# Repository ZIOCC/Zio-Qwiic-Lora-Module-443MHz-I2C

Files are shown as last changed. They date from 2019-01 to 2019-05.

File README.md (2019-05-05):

# Zio-Qwiic-Lora-Module-443MHz-I2C

The gateway firmware referred [Sparkfun's QwiicRF](https://github.com/sparkfunx/Qwiic_RF)

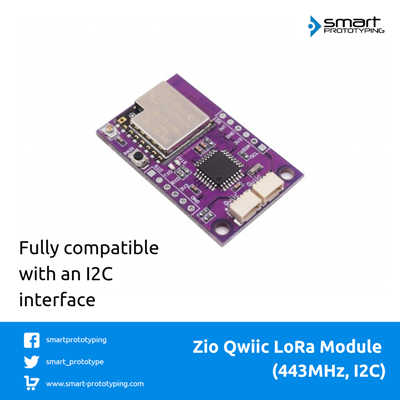
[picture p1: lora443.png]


> This product can be available for purchase [here](https://www.smart-prototyping.com/Zio-Qwiic-Lora-module-443MHz-I2C).

##### Description

This is a [Qwiic](https://www.smart-prototyping.com/Qwiic.html) version LoRa module, no soldering and jumper wire connections, just [Qwiic cable](https://www.smart-prototyping.com/zio-cables) plugin, and have fun! 

LoRa module is powerful, it can send and receive data packets at up to 10KM distance, and consumes very low power (10mA for receiver, 120mA for transmitter).

LoRa itself is a SPI device, in order to turn it into a I2C device, we added an MCU as the gateway to do the dirty work for you, you just need to use the module’s I2C interface to communicate with the others. It is just that easy.

> Note: This LoRa module is based on the LoRa-01 module, the frequency range is 420 - 450 MHz, check [here](https://www.thethingsnetwork.org/docs/lorawan/frequencies-by-country.html) to see if this can be used in your country.

##### Specification

* Voltage: 3.3V
* Interface: I2C
* I2C Address: 0x35, 0x36 (Default: 0x35)
* Distance: Up to 10KM
* Gateway MCU: ATMEGA328P
* Dimension: 26.0 x 41.6 mm
* Weight: 5.3g

##### Links

* [PCB Source file](https://github.com/ZIOCC/Zio-Qwiic-Lora-Module-443MHz-I2C/tree/master/EAGLE)
* [PCB schematic](https://github.com/ZIOCC/Zio-Qwiic-Lora-Module-443MHz-I2C/blob/master/zio%20qwiic%20lora%20module%20433%20schematic.pdf)
* [Demo code](https://github.com/sparkfun/SparkFun_QwiicRF_Library/)
* [Gateway firmware](https://github.com/ZIOCC/Zio-Qwiic-Lora-Module-443MHz-I2C/tree/master/Gateway_Firmware/Qwiic_RF_I2C_Pairing)

> ###### About Zio
> Zio is a new line of open sourced, compact, and grid layout boards, fully integrated for Arduino and Qwiic ecosystem. Designed ideally for wearables, robotics, small-space limitations or other on the go projects. Check out other awesome Zio products [here](https://www.smart-prototyping.com/Zio).

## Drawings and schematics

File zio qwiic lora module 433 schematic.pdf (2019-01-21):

# GND¹⁰⁰nF ±10% ⁵⁰V

# ATMEGA328P ¹⁰K ±1%

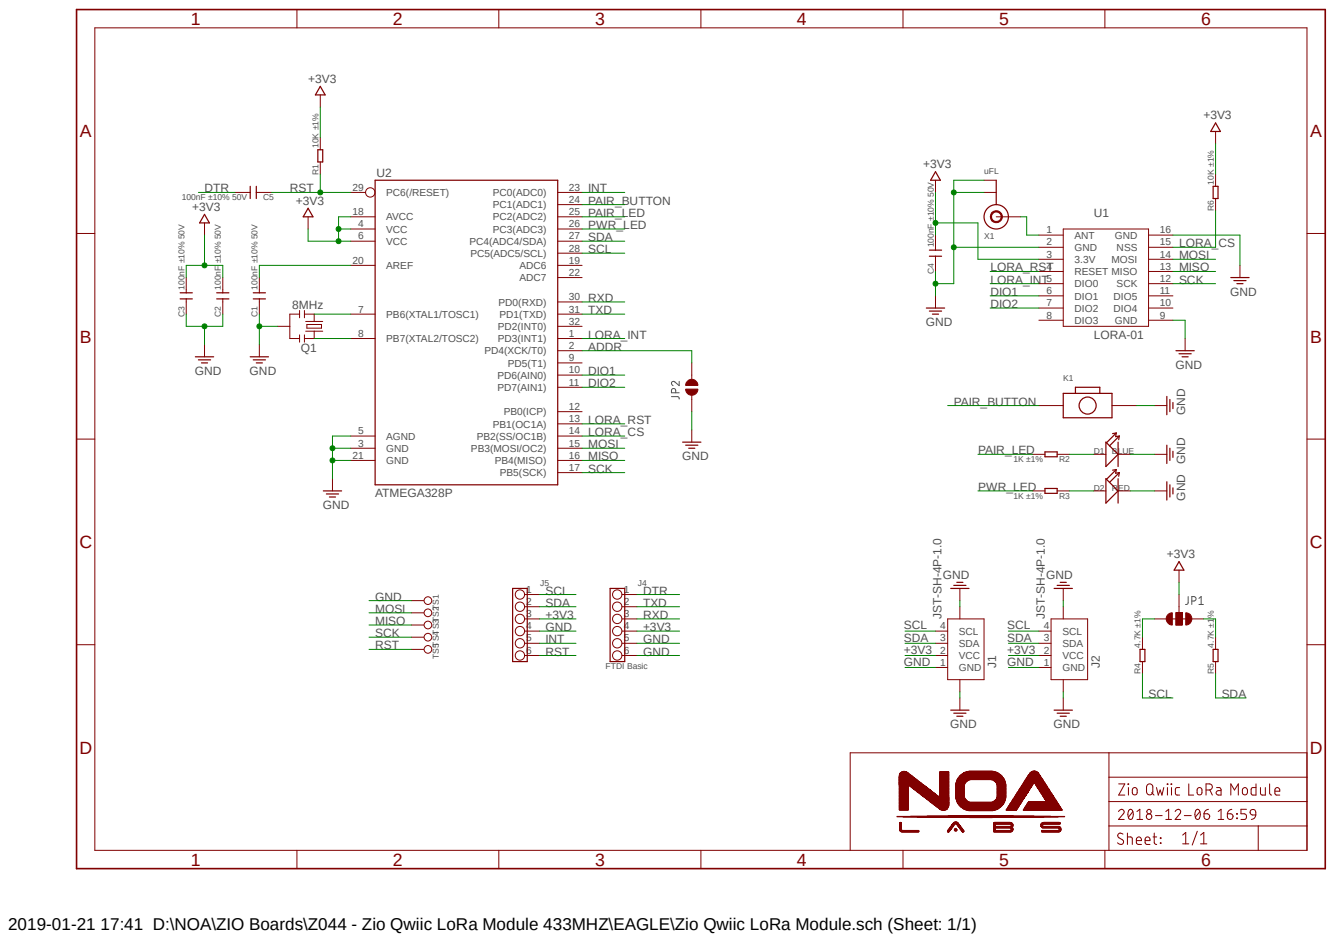
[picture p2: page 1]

2019-01-21 17:41 D:\NOA\ZIO Boards\Z044 - Zio Qwiic LoRa Module 433MHZ\EAGLE\Zio Qwiic LoRa Module.sch (Sheet: 1/1)

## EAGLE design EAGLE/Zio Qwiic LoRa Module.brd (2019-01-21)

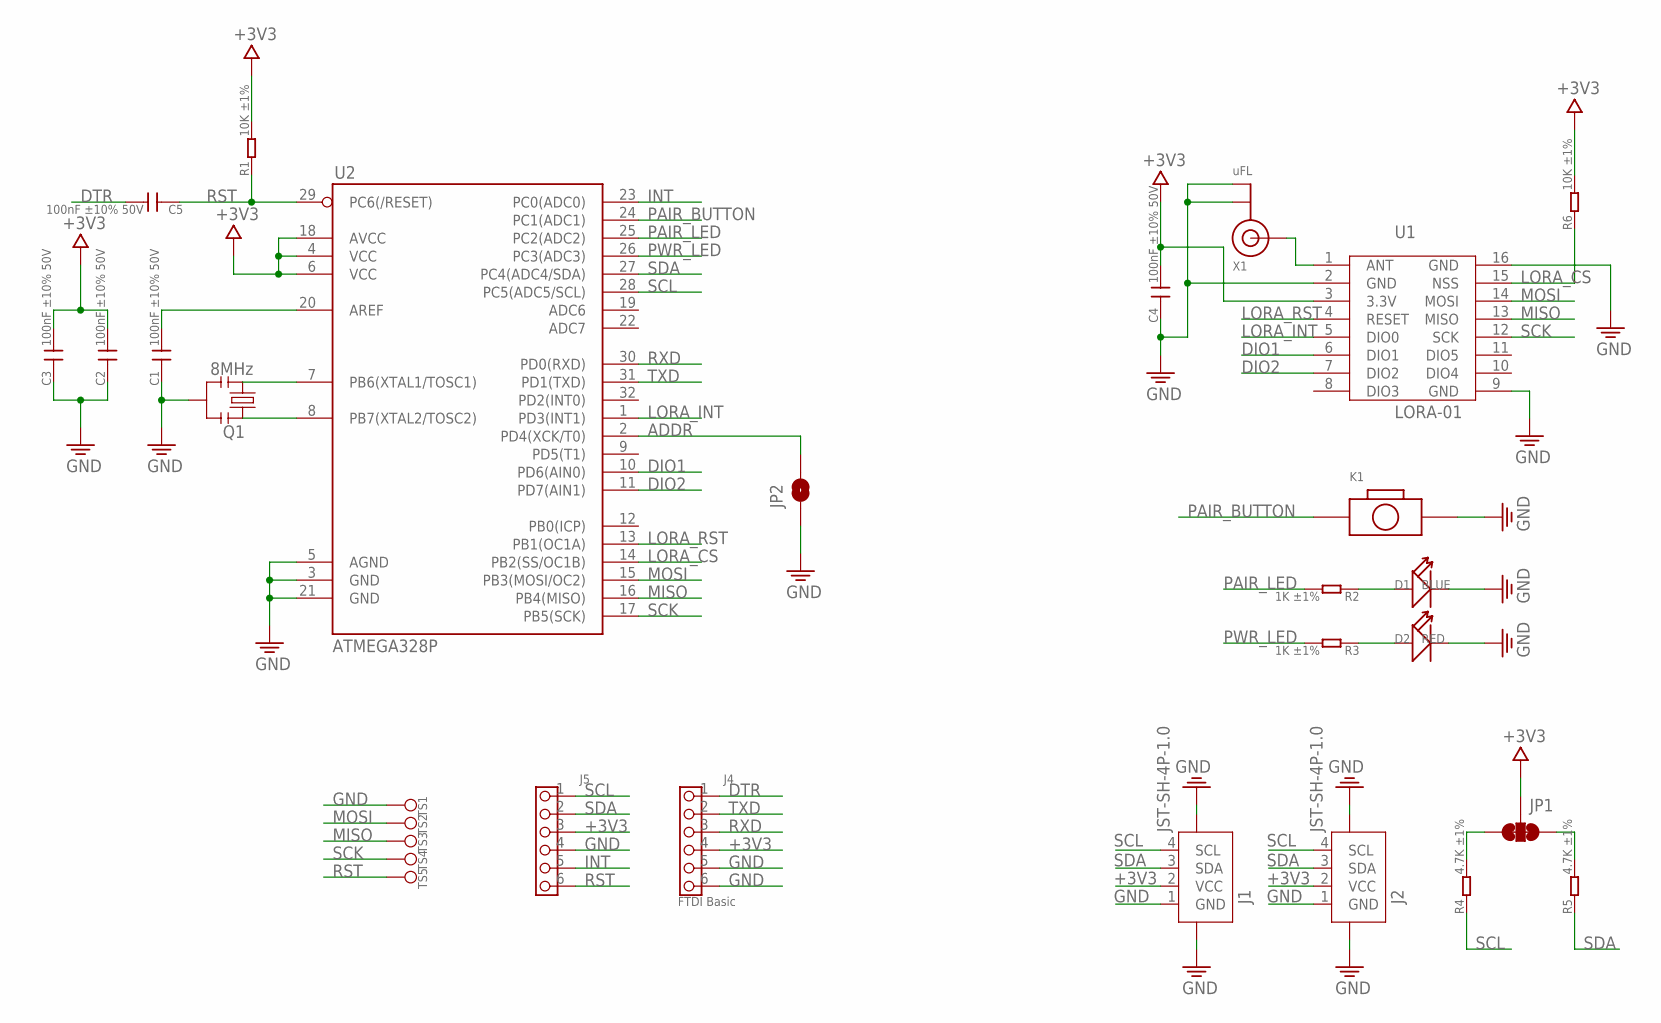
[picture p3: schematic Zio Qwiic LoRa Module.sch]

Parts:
C1, C2, C3, C4, C5: 100nF ±10% 50V; C0603
D1: BLUE; LED-0603
D2: RED; LED-0603
J1, J2: JST-SH-4P-1.0; JST-SH-4P
J4: FTDI Basic; 6P-2.54-60/35MIL
J5: HEADER-6P-60/35MIL; 6P-2.54-60/35MIL
JP1: SMT-JUMPER_3_2-NC_TRACE
JP2: JUMPER-SMT_2_NC_PASTE_NOCREM; SMT-JUMPER_2_NC_PASTE_SILK_NOCREM
K1: BOTTON-2PSKRKAEE020; SKRKAEE020
Q1: 8MHz; RESONATOR-SMD
R1, R6: 10K ±1%; R0603
R2, R3: 1K ±1%; R0603
R4, R5: 4.7K ±1%; R0603
TS1, TS2, TS3, TS4, TS5: TEST_POINT35MIL; 1P-35MIL
U1: LORA-01
U2: ATMEGA328P; TQFP32-08
X1: uFL; U.FL

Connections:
+3V3: C2.2, C3.2, C4.2, J1.2 (VCC), J2.2 (VCC), J4.4, J5.3, JP1.2, R1.2, R6.2, U1.3 (3.3V), U2.4 (VCC), U2.6 (VCC), U2.18 (AVCC)
ADDR: JP2.2, U2.2 (PD4(XCK/T0))
DIO1: U1.6 (DIO1), U2.10 (PD6(AIN0))
DIO2: U1.7 (DIO2), U2.11 (PD7(AIN1))
DTR: C5.2, J4.1
GND: C1.1, C2.1, C3.1, C4.1, D1.-, D2.-, J1.1 (GND), J1.NC1 (5), J1.NC2 (6), J2.1 (GND), J2.NC1 (5), J2.NC2 (6), J4.5, J4.6, J5.4, JP2.1, K1.2, Q1.2, TS1.P$1, U1.2 (GND), U1.9 (GND), U1.16 (GND), U2.3 (GND), U2.5 (AGND), U2.21 (GND), X1.1 (GND), X1.2 (GND)
INT: J5.5, U2.23 (PC0(ADC0))
LORA_CS: R6.1, U1.15 (NSS), U2.14 (PB2(SS/OC1B))
LORA_INT: U1.5 (DIO0), U2.1 (PD3(INT1))
LORA_RST: U1.4 (RESET), U2.13 (PB1(OC1A))
MISO: TS3.P$1, U1.13 (MISO), U2.16 (PB4(MISO))
MOSI: TS2.P$1, U1.14 (MOSI), U2.15 (PB3(MOSI/OC2))
unnamed: D1.+, R2.1
unnamed: D2.+, R3.1
unnamed: Q1.3, U2.7 (PB6(XTAL1/TOSC1))
unnamed: Q1.1, U2.8 (PB7(XTAL2/TOSC2))
unnamed: C1.2, U2.20 (AREF)
unnamed: U1.1 (ANT), X1.3 (SIGNAL)
unnamed: JP1.3, R4.2
unnamed: JP1.1, R5.2
PAIR_BUTTON: K1.1, U2.24 (PC1(ADC1))
PAIR_LED: R2.2, U2.25 (PC2(ADC2))
PWR_LED: R3.2, U2.26 (PC3(ADC3))
RST: C5.1, J5.6, R1.1, TS5.P$1, U2.29 (PC6(/RESET))
RXD: J4.3, U2.30 (PD0(RXD))
SCK: TS4.P$1, U1.12 (SCK), U2.17 (PB5(SCK))
SCL: J1.4 (SCL), J2.4 (SCL), J5.1, R4.1, U2.28 (PC5(ADC5/SCL))
SDA: J1.3 (SDA), J2.3 (SDA), J5.2, R5.1, U2.27 (PC4(ADC4/SDA))
TXD: J4.2, U2.31 (PD1(TXD))

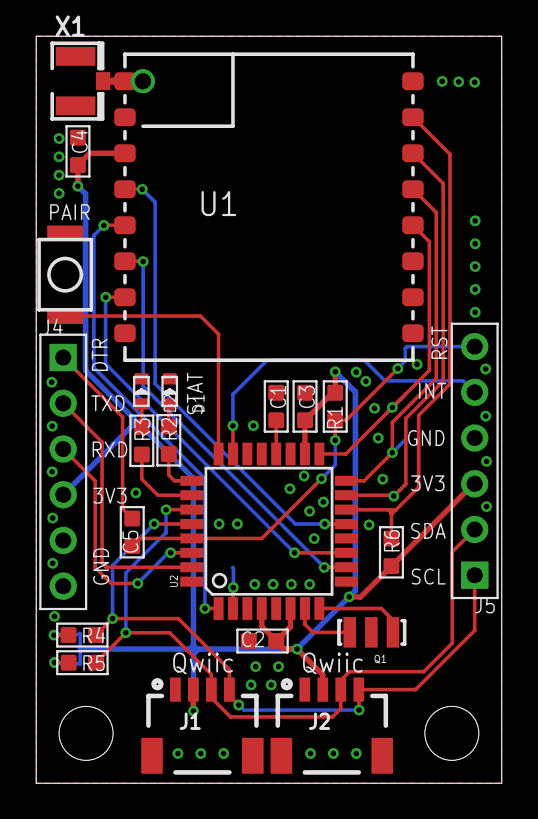
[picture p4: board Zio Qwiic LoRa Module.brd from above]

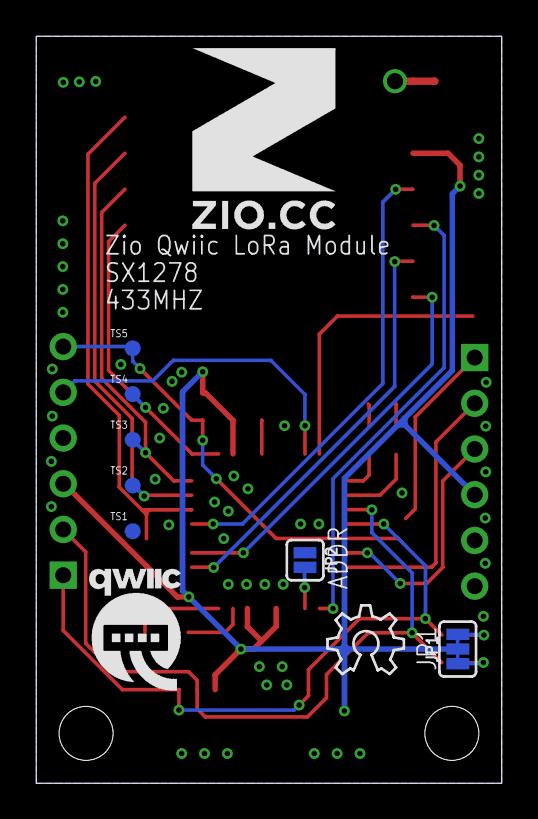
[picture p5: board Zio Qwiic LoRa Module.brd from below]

Board: 2 copper layers, 25.9 x 41.5 mm, 32 parts (10 on the bottom side), 29 nets.

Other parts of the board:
U$10: 10MM
U$11: QWIIC-LOGO-MEDIUM
U$12: OSHW_6X150_NOTEXT

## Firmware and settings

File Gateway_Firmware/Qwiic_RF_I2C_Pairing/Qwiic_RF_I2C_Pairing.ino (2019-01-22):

#include <Wire.h> //Need this for I2C
#include <EEPROM.h> //Need this for EEPROM Read/Write
#include <SPI.h> //Need this to talk to the radio
#include <LoRa.h> //https://github.com/sandeepmistry/arduino-LoRa

//Location in EEPROM where various settings will be stored
#define LOCATION_I2C_ADDR 0x01
#define LOCATION_RADIO_ADDR 0x02
#define LOCATION_SYNC_WORD 0x03
#define LOCATION_SPREAD_FACTOR 0x04
#define LOCATION_MESSAGE_TIMEOUT 0x05
#define LOCATION_TX_POWER 0x06
#define LOCATION_PAIRED_ADDRESS 0x07

//There is an ADR jumpber on this board. When closed, forces I2C address to default.
#define I2C_ADDRESS_DEFAULT 0x35
#define I2C_ADDRESS_JUMPER_CLOSED 0x36

//These are the commands we understand and may respond to
#define COMMAND_GET_STATUS 0x01
#define COMMAND_SEND 0x02
#define COMMAND_SEND_RELIABLE 0x03
#define COMMAND_SET_RELIABLE_TIMEOUT 0x04
#define COMMAND_GET_PAYLOAD 0x05
#define COMMAND_SET_SPREAD_FACTOR 0x06
#define COMMAND_SET_SYNC_WORD 0x07
#define COMMAND_GET_SYNC_WORD 0x11
#define COMMAND_SET_RF_ADDRESS 0x08
#define COMMAND_GET_RF_ADDRESS 0x09
#define COMMAND_GET_PACKET_RSSI 0x0A
#define COMMAND_GET_PAYLOAD_SIZE 0x0B
#define COMMAND_GET_PACKET_SENDER 0x0C
#define COMMAND_GET_PACKET_RECIPIENT 0x0D
#define COMMAND_GET_PACKET_SNR 0x0E
#define COMMAND_GET_PACKET_ID 0x0F
#define COMMAND_SET_TX_POWER 0x10
#define COMMAND_SET_I2C_ADDRESS 0x20
#define COMMAND_SET_PAIRED_ADDRESS 0x12
#define COMMAND_GET_PAIRED_ADDRESS 0x13
#define COMMAND_GET_SKU 0x15
#define COMMAND_SEND_PAIRED 0x20
#define COMMAND_SEND_RELIABLE_PAIRED 0x30

//These will help us keep track of how to respond to requests
#define RESPONSE_TYPE_STATUS 0x00
#define RESPONSE_TYPE_PAYLOAD 0x01
#define RESPONSE_TYPE_RF_ADDRESS 0x02
#define RESPONSE_TYPE_PACKET_RSSI 0x03
#define RESPONSE_TYPE_PACKET_SIZE 0x04
#define RESPONSE_TYPE_PACKET_SENDER 0x05
#define RESPONSE_TYPE_PACKET_RECIPIENT 0x06
#define RESPONSE_TYPE_PACKET_SNR 0x07
#define RESPONSE_TYPE_PACKET_ID 0x08
#define RESPONSE_TYPE_SYNC_WORD 0x09
#define RESPONSE_TYPE_PAIRED_ADDRESS 0x10
#define RESPONSE_TYPE_SKU 0x11

//A Few Pin Definitions
#define ADR_JUMPER 4
#define PAIR_BTN A1
#define PAIR_LED A2
#define PWR_LED A3

//Firmware version. This is sent when requested. Helpful for tech support.
const byte firmwareVersionMajor = 0;
const byte firmwareVersionMinor = 5;
char SKU[] = "14788";

//RFM95 pins
const int csPin = 10;          // LoRa radio chip select
const int resetPin = 9;       // LoRa radio reset
const int irqPin = 3;         // change for your board; must be a hardware interrupt pin

//*** These get twiddled during interrupts so they're type volatile ***

//System status variable
//Bit 0 - Ready To Send
//Bit 1 - Packet Available
//Bit 2 - Waiting on Reliable Send
//Bit 3 - Reliable Send Timeout
volatile byte systemStatus = 0b00000000;
//This global is used to keep track of the I2C Address (Software Switchable)
volatile byte settingI2CAddress = I2C_ADDRESS_DEFAULT;
//These globals are used for the "Reliable Send" routine
volatile unsigned long reliableSendTime = 0x00;
volatile unsigned long reliableResend = 0x00;
volatile byte reliableSendChk = 0x00;

//*** ***

//These are the radio parameters that are used to
//Initialize the RFM95. We assign them default
//values so we can load EEPROM on first boot.
byte settingRFAddress = 0xBB;
byte settingSyncWord = 0x34;
byte settingSpreadFactor = 0x07;
byte settingMessageTimeout = 0x0A;
byte settingTXPower = 0x11;
byte settingPairedAddress = 0xBB;
byte msgCount = 0x00;

//This is a type for storing radio packets
typedef struct {
  byte id;
  byte sender;
  byte recipient;
  byte snr;
  byte rssi;
  byte reliable;
  byte payloadLength;
  String payload;
} packet;

//Let's initialize a few instances of our new type
packet lastReceived = {0, 0, 0, 0, 0, 0, 0, ""};
packet lastSent = {0, 0, 0, 0, 0, 0, 0, ""};
packet outbox = {0, 0, 0, 0, 0, 0, 0, ""};

//Counter for the Pairing Button Hold-down
uint16_t pair_hold = 0;

//This will help us keep track of how to respond to requests
byte responseType = RESPONSE_TYPE_STATUS;

//This flag will tell the main loop when an outgoing packet is waiting for the radio
boolean outbox_waiting = 0;

//This flag will tell the main loop to mark the beginning of a reliable send cycle
boolean mark_time_reliable = 0;

void setup()
{
    
  //Set pin modes
  pinMode(PAIR_BTN, INPUT_PULLUP);
  pinMode(ADR_JUMPER, INPUT_PULLUP);
  pinMode(PAIR_LED, OUTPUT);
  pinMode(PWR_LED, OUTPUT);

  readSystemSettings(); //Load all system settings from EEPROM

  // override the default CS, reset, and IRQ pins (optional)
  LoRa.setPins(csPin, resetPin, irqPin);// set CS, reset, IRQ pin

  if (!LoRa.begin(433E6)) { //Initialize ratio at 433 MHz
    while (true) {
      //If failed, blink power LED
      digitalWrite(PWR_LED, 1);
      delay(500);
      digitalWrite(PWR_LED, 0);
      delay(500);
    };
  } else {
    //If successful, light power LED
    digitalWrite(PWR_LED, 1);
  }

  //Set our radio parameters from the stored values
  LoRa.setSyncWord(settingSyncWord);
  LoRa.setSpreadingFactor(settingSpreadFactor);
  LoRa.setTxPower(settingTXPower);

  LoRa.enableCrc();

  //Begin listening on I2C only after we've setup all our config and opened any files
  startI2C(); //Determine the I2C address we should be using and begin listening on I2C bus
  systemStatus |= 1 << 0; //Set "Ready" Status Flag
}

void loop()
{

  //If we just started a reliable send cycle, we need to mark the start time.
  //We do it here instead of immediately after getting the command so that we aren't
  //loading an unsigned long during an ISR
  if (mark_time_reliable) {
    systemStatus |= 1 << 2; //Set "Waiting on Reliable Send" Status Flag
    reliableSendTime = reliableResend = millis();
    mark_time_reliable = 0;
  }

  //If there is a "Waiting on Reliable Send" flag and the ack timer has expired,
  //remove the flag and set the "Reliable Send Timeout" flag instead.
  if ( ( (systemStatus >> 2) & 1 ) && ( millis() > ( reliableSendTime + ( settingMessageTimeout * 1000 ) ) ) ) {
    systemStatus &= ~(1 << 2); //Clear "Waiting on Reliable Send" Status Flag
    systemStatus |= 1 << 0; //Set "Ready" Status Flag
    systemStatus |= 1 << 3; //Set "Reliable Send Timeout" Status Flag
    reliableSendChk = 0x00; //Reset Checksum accumulator
    reliableSendTime = 0x00; //Reset reliableSendTime timestamp
    reliableResend = 0x00; //Reset reliableResend timestamp
    //If there is a "Waiting on Reliable Send" flag and the ack timer has NOT expired,
    //check the reliable send interval counter and possibly try resending.
  } else if ( ( (systemStatus >> 2) & 1 ) && ( millis() < ( reliableSendTime + ( settingMessageTimeout * 1000 ) ) ) ) {
    if ( millis() > reliableResend + 1000 ) { //Retry once per second
      sendMessage(lastSent.recipient, 0, lastSent.payload);
      reliableResend = millis();
    }
  }

  //If the pairing button is being held
  if ( digitalRead(PAIR_BTN) == 0 ) {
    pair_hold++;
    if (pair_hold > 5000) {
      pair_hold = 0;
      pairingSequence();
    }
  } else {
    pair_hold = 0;
  }

  if (outbox_waiting) {
    sendMessage(outbox.recipient, outbox.reliable, outbox.payload);
    outbox_waiting = 0;
    systemStatus |= 1 << 0; //Set "Ready" Status Flag
  }

  onReceive(LoRa.parsePacket());
}

//Send a message via the radio
void sendMessage(byte destination, byte reliable, String outgoing)
{
  digitalWrite(PAIR_LED, 1);
  LoRa.beginPacket();                   // start packet
  LoRa.write(destination);              // add destination address
  LoRa.write(settingRFAddress);         // add sender address
  LoRa.write(msgCount);                 // add message ID
  LoRa.write(reliable);                 // add reliable send tag
  LoRa.write(outgoing.length());        // add payload length
  LoRa.print(outgoing);                 // add payload
  LoRa.endPacket();                     // finish packet and send it

  lastSent.id = msgCount;
  lastSent.sender = settingRFAddress;
  lastSent.recipient = destination;
  lastSent.payloadLength = outgoing.length();
  lastSent.payload = outgoing;
  lastSent.reliable = reliable;

  msgCount++;                           // increment message ID
  digitalWrite(PAIR_LED, 0);
}

//Check for a new radio packet, parse it, store it
void onReceive(int packetSize) {
  if (packetSize == 0) return;          // if there's no packet, return

  digitalWrite(PAIR_LED, 1);
  // read packet header bytes:
  int recipient = LoRa.read();          // recipient address
  byte sender = LoRa.read();            // sender address
  byte incomingMsgId = LoRa.read();     // incoming msg ID
  byte reliable = LoRa.read();          // reliable send tag
  byte incomingLength = LoRa.read();    // incoming msg length

  String incoming = "";

  while (LoRa.available()) {
    incoming += (char)LoRa.read();
  }

  digitalWrite(PAIR_LED, 0);

  if (incomingLength != incoming.length()) {   // check length for error
    return; //Get outta here
  }

  //If the packet isn't addressed to this device or the broadcast channel,
  if (recipient != settingRFAddress && recipient != 0xFF) {
    return; //Get outta here
  }

  //If the message is for this device, or broadcast, store it appropriately:
  lastReceived.id = incomingMsgId;
  lastReceived.sender = sender;
  lastReceived.recipient = recipient;
  lastReceived.snr = LoRa.packetSnr();
  lastReceived.rssi = LoRa.packetRssi();
  lastReceived.payloadLength = incomingLength;
  lastReceived.payload = incoming;
  lastReceived.reliable = reliable;

  //If we're waiting on a Reliable Send ack, check to see if this is it.
  //A Reliable Send Ack payload has two bytes:
  //Byte 1: SNR of Reliable Packet
  //Byte 2: RSSI of Reliable Packet
  if ( (systemStatus >> 2) & 1 ) {

    //If the fourth byte of the header is equal to the sum of
    //the last sent message, we have Reliable Ack.
    if ( reliable == reliableSendChk ) {

      reliableSendChk = 0x00; //Reset Checksum accumulator
      reliableSendTime = 0x00; //Reset reliableSendTime timestamp
      reliableResend = 0x00; //Reset reliableResend timestamp
      systemStatus &= ~(1 << 2); //Clear "Waiting on Reliable Send" Status Flag
      systemStatus |= 1 << 0; //Set "Ready" Status Flag
      systemStatus &= ~(1 << 3); //Clear "Reliable Send Timeout" Status Flag

      //Grab these tidbits in case anyone wants them
      lastSent.snr = incoming.charAt(0);
      lastSent.rssi = incoming.charAt(1);

    }
  }

  //If this was a Reliable type message, calculate checksum and reply
  if ( reliable == 1 ) {

    String response = "";
    byte reliableAckChk = 0;
    //Calculate simple checksum of payload, reliableSendChk is type byte
    //so for sake of cycles, we will let it roll instead of explicitly
    //calculating (sum payload % 256)
    for ( int symbol = 0; symbol < incomingLength; symbol++ ) {
      reliableAckChk += incoming.charAt(symbol);
    }
    //Because we use values 0 and 1 for signalling, we ensure that the
    //checksum can never be < 1
    if ( reliableAckChk < 254 ) {
      reliableAckChk += 2;
    }
    response = lastReceived.snr;
    response += lastReceived.rssi;
    //Return to Sender
    sendMessage(sender, reliableAckChk, response);

  }

  //Set the "New Payload" Status Flag
  systemStatus |= 1 << 1;
}

//Read an I2C Request from the master
void receiveEvent(int numberOfBytesReceived)
{
  //Record bytes to local array
  byte incoming = Wire.read();

  //Set new I2C address
  if (incoming == COMMAND_SET_I2C_ADDRESS)
  {
    if (Wire.available())
    {
      settingI2CAddress = Wire.read();

      //Error check
      if (settingI2CAddress < 0x08 || settingI2CAddress > 0x77)
        return; //Command failed. This address is out of bounds.

      EEPROM.write(LOCATION_I2C_ADDR, settingI2CAddress);

      //Our I2C address may have changed because of user's command
      startI2C(); //Determine the I2C address we should be using and begin listening on I2C bus
    }
  }
  //Return the current system status
  else if (incoming == COMMAND_GET_STATUS)
  {
    responseType = RESPONSE_TYPE_STATUS;
  }
  //Send a payload via the radio
  else if (incoming == COMMAND_SEND)
  {

    if (Wire.available() > 1) {

      byte recipient = Wire.read();

      String payload = "";

      while (Wire.available()) {
        payload += (char)Wire.read();
      }

      queueMessage(recipient, 0, payload);

    }

  }
  //Send a payload via the radio to the last
  //paired address
  else if (incoming == COMMAND_SEND_PAIRED)
  {

    if (Wire.available() > 1) {

      String payload = "";

      while (Wire.available()) {
        payload += (char)Wire.read();
      }

      queueMessage(settingPairedAddress, 0, payload);

    }

  }  
  //Send a payload via the radio and request ack
  else if (incoming == COMMAND_SEND_RELIABLE)
  {

    if (Wire.available() > 1) {

      byte recipient = Wire.read();

      String payload = "";

      while (Wire.available()) {
        payload += (char)Wire.read();
      }

      queueMessage(recipient, 1, payload);

      //Reset checksum accumulator
      reliableSendChk = 0;

      //Calculate simple checksum of payload, reliableSendChk is type byte
      //so for sake of cycles, we will let it roll instead of explicitly
      //calculating (sum payload % 256)
      for ( int symbol = 0; symbol < payload.length(); symbol++ ) {
        reliableSendChk += payload.charAt(symbol);
      }

      //Because we use values 0 and 1 for signalling, we ensure that the
      //checksum can never be < 1
      if ( reliableSendChk < 254 ) {
        reliableSendChk += 2;
      }

      mark_time_reliable = 1;

    }

  }
  //Send a payload via the radio to the last paired
  //address and request ack
  else if (incoming == COMMAND_SEND_RELIABLE_PAIRED)
  {

    if (Wire.available() > 1) {

      String payload = "";

      while (Wire.available()) {
        payload += (char)Wire.read();
      }

      queueMessage(settingPairedAddress, 1, payload);

      //Reset checksum accumulator
      reliableSendChk = 0;

      //Calculate simple checksum of payload, reliableSendChk is type byte
      //so for sake of cycles, we will let it roll instead of explicitly
      //calculating (sum payload % 256)
      for ( int symbol = 0; symbol < payload.length(); symbol++ ) {
        reliableSendChk += payload.charAt(symbol);
      }

      //Because we use values 0 and 1 for signalling, we ensure that the
      //checksum can never be < 1
      if ( reliableSendChk < 254 ) {
        reliableSendChk += 2;
      }

      mark_time_reliable = 1;

    }

  }  
  //Set the time in seconds to wait for reliable ack before failing
  else if (incoming == COMMAND_SET_RELIABLE_TIMEOUT)
  {

    if (Wire.available()) {
      settingMessageTimeout = Wire.read();
      EEPROM.write(LOCATION_MESSAGE_TIMEOUT, settingMessageTimeout);
    }

  }
  //Store the address of a paired radio
  else if (incoming == COMMAND_SET_PAIRED_ADDRESS)
  {

    if (Wire.available()) {
      settingPairedAddress = Wire.read();
      EEPROM.write(LOCATION_PAIRED_ADDRESS, settingPairedAddress);
    }

  }
  //Return the address of a paired radio
  else if (incoming == COMMAND_GET_PAIRED_ADDRESS)
  {

    responseType = RESPONSE_TYPE_PAIRED_ADDRESS;

  }  
  //Return the payload of the last received packet
  else if (incoming == COMMAND_GET_PAYLOAD)
  {

    responseType = RESPONSE_TYPE_PAYLOAD;

  }
  //Set the spread factor of the radio
  else if (incoming == COMMAND_SET_SPREAD_FACTOR)
  {

    if (Wire.available()) {
      byte newSpreadFactor = Wire.read();

      if (newSpreadFactor > 12 || newSpreadFactor < 6) {
        return;
      }

      settingSpreadFactor = newSpreadFactor;
      EEPROM.write(LOCATION_SPREAD_FACTOR, settingSpreadFactor);
      LoRa.setSpreadingFactor(settingSpreadFactor);
    }

  }
  //Set the Sync Word of the radio
  else if (incoming == COMMAND_SET_SYNC_WORD)
  {
    if (Wire.available()) {
      settingSyncWord = Wire.read();
      EEPROM.write(LOCATION_SYNC_WORD, settingSyncWord);
      LoRa.setSyncWord(settingSyncWord);
    }

  }
  //Set the Address of the radio
  else if (incoming == COMMAND_SET_RF_ADDRESS)
  {

    if (Wire.available()) {
      byte newRFAddress = Wire.read();

      if (newRFAddress < 0xFF) { //0xFF is Broadcast Channel
        settingRFAddress = newRFAddress;
        EEPROM.write(LOCATION_RADIO_ADDR, settingRFAddress);
      }
    }

  }
  //Return the Address of the radio
  else if (incoming == COMMAND_GET_RF_ADDRESS)
  {

    responseType = RESPONSE_TYPE_RF_ADDRESS;
    return;

  }
  //Return the RSSI of the last received packet
  else if (incoming == COMMAND_GET_PACKET_RSSI)
  {

    responseType = RESPONSE_TYPE_PACKET_RSSI;
    return;

  }
  //Return the size of the payload of the last received packet
  else if (incoming == COMMAND_GET_PAYLOAD_SIZE)
  {

    responseType = RESPONSE_TYPE_PACKET_SIZE;
    return;

  }
  //Return the origin address of the last received packet
  else if (incoming == COMMAND_GET_PACKET_SENDER)
  {

    responseType = RESPONSE_TYPE_PACKET_SENDER;
    return;

  }
  //Return the destination address of the last received packet
  else if (incoming == COMMAND_GET_PACKET_RECIPIENT)
  {

    responseType = RESPONSE_TYPE_PACKET_RECIPIENT;
    return;

  }
    else if (incoming == COMMAND_GET_SYNC_WORD)
  {

    responseType = RESPONSE_TYPE_SYNC_WORD;
    return;

  }
  //Return the SNR (Signal-to-Noise Ratio) of the last received packet
  else if (incoming == COMMAND_GET_PACKET_SNR)
  {

    responseType = RESPONSE_TYPE_PACKET_SNR;
    return;

  }
  //Return the sequential ID of the last received packet
  else if (incoming == COMMAND_GET_PACKET_ID)
  {

    responseType = RESPONSE_TYPE_PACKET_ID;
    return;

  }
  //Return the SKU of this product. Used to identify
  //other radios on the bus during pairing operations.
  else if (incoming == COMMAND_GET_SKU)
  {

    responseType = RESPONSE_TYPE_SKU;
    return;

  }
  //Adjust the radio transmit amplifier
  else if (incoming == COMMAND_SET_TX_POWER)
  {

    byte txPower = Wire.read();
    if (txPower > 17) {
      txPower = 17;
    }
    settingTXPower = txPower;
    EEPROM.write(LOCATION_TX_POWER, settingTXPower);
    LoRa.setTxPower(txPower);

  }
}

//Respond to I2C master's request for bytes
void requestEvent()
{
  //Return system status byte
  if (responseType == RESPONSE_TYPE_STATUS)
  {
    Wire.write(systemStatus);
  }
  //Return payload of last received packet
  else if (responseType == RESPONSE_TYPE_PAYLOAD)
  {

    for (byte len = 0; len < lastReceived.payloadLength; len++) {
      Wire.write(lastReceived.payload.charAt(len));
    }

    responseType = RESPONSE_TYPE_STATUS;
    systemStatus &= ~(1 << 1); //Clear "New Payload" Status Flag
  }
  //Return current local address
  else if (responseType == RESPONSE_TYPE_RF_ADDRESS)
  {
    Wire.write(settingRFAddress);
    responseType = RESPONSE_TYPE_STATUS;
  }  
  else if (responseType == RESPONSE_TYPE_SYNC_WORD)
  {
    Wire.write(settingSyncWord);
    responseType = RESPONSE_TYPE_STATUS;
  }
  //Return the RSSI of the last received packet
  else if (responseType == RESPONSE_TYPE_PACKET_RSSI)
  {
    Wire.write(lastReceived.rssi);
    responseType = RESPONSE_TYPE_STATUS;
  }
  //Return the size of the payload in the last received packet
  else if (responseType == RESPONSE_TYPE_PACKET_SIZE)
  {
    Wire.write(lastReceived.payloadLength);
    responseType = RESPONSE_TYPE_STATUS;
  }
  //Return the origin address of the last received packet
  else if (responseType == RESPONSE_TYPE_PACKET_SENDER)
  {
    Wire.write(lastReceived.sender);
    responseType = RESPONSE_TYPE_STATUS;
  }
  //Return the destination address of the last received packet
  else if (responseType == RESPONSE_TYPE_PACKET_RECIPIENT)
  {
    Wire.write(lastReceived.recipient);
    responseType = RESPONSE_TYPE_STATUS;
  }
  //Return the SNR (Signal-to-Noise Ratio) of the last received packet
  else if (responseType == RESPONSE_TYPE_PACKET_SNR)
  {
    Wire.write(lastReceived.snr);
    responseType = RESPONSE_TYPE_STATUS;
  }
  //Return the sequential ID of the last received packet
  else if (responseType == RESPONSE_TYPE_PACKET_ID)
  {
    Wire.write(lastReceived.id);
    responseType = RESPONSE_TYPE_STATUS;
  }
  else if (responseType == RESPONSE_TYPE_PAIRED_ADDRESS)
  {
    Wire.write(settingPairedAddress);
    responseType = RESPONSE_TYPE_STATUS;
  }  
  //This is used to identify other radios on the bus during
  //pairing operations.
  else if (responseType == RESPONSE_TYPE_SKU)
  {
    Wire.write(SKU, 5);
    responseType = RESPONSE_TYPE_STATUS;
  }  
  else //By default we respond with the system status    
  {
    Wire.write(systemStatus);
  }
}

//Restore radio parameters or defaults
void readSystemSettings(void)
{

  //If this is the first ever boot, or EEPROM was nuked, load defaults to EEPROM:
  if ( EEPROM.read(LOCATION_RADIO_ADDR) == 0xFF ) {

    EEPROM.write(LOCATION_I2C_ADDR, I2C_ADDRESS_DEFAULT);
    EEPROM.write(LOCATION_RADIO_ADDR, settingRFAddress);
    EEPROM.write(LOCATION_SYNC_WORD, settingSyncWord);
    EEPROM.write(LOCATION_SPREAD_FACTOR, settingSpreadFactor);
    EEPROM.write(LOCATION_MESSAGE_TIMEOUT, settingMessageTimeout);
    EEPROM.write(LOCATION_TX_POWER, settingTXPower);
    EEPROM.write(LOCATION_PAIRED_ADDRESS, settingPairedAddress);
    
    //If not, load radio paramters from EEPROM
  } else {

    settingRFAddress = EEPROM.read(LOCATION_RADIO_ADDR);
    settingSyncWord = EEPROM.read(LOCATION_SYNC_WORD);
    settingSpreadFactor = EEPROM.read(LOCATION_SPREAD_FACTOR);
    settingMessageTimeout = EEPROM.read(LOCATION_MESSAGE_TIMEOUT);
    settingTXPower = EEPROM.read(LOCATION_TX_POWER);
    settingPairedAddress = EEPROM.read(LOCATION_PAIRED_ADDRESS);

  }
}
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

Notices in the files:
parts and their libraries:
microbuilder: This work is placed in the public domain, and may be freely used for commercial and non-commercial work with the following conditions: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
